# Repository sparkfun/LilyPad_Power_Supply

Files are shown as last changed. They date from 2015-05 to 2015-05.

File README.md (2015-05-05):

LilyPad Power Supply
========================================

LilyPad Power Supply

[*LilyPad Power Supply (DEV-11259)*](https://www.sparkfun.com/products/11259)

A small, but mighty power supply. This board was designed to be as small and inconspicuous as possible. 
Pop in a AAA battery, flip the power switch, and you will have a 5V supply to power your LilyPad circuit. 
Good up to 200mA. Short circuit protected.

Repository Contents
-------------------
 
* **/Hardware** - Eagle design files (.brd, .sch)
* **/Production** - Production panel files (.brd)

Documentation
--------------
* **[SparkFun Fritzing repo](https://github.com/sparkfun/Fritzing_Parts)** - Fritzing diagrams for SparkFun products.
* **[SparkFun 3D Model repo](https://github.com/sparkfun/3D_Models)** - 3D models of SparkFun products. 

License Information
-------------------
This product is _**open source**_! 

The **hardware** is released under [Creative Commons ShareAlike 4.0 International](https://creativecommons.org/licenses/by-sa/4.0/).

Please use, reuse, and modify these files as you see fit. Please maintain attribution to SparkFun Electronics and release anything derivative under the same license.

Distributed as-is; no warranty is given.

- Your friends at SparkFun.

_**Note:** A portion of this sale is given back to Dr. Leah Buechley for continued development and education of e-textiles._

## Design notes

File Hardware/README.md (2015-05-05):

SparkFun <PRODUCT NAME> Design Files
=====================================

The .sch and .brd files hare are Eagle CAD schematic and PCB design files from SparkFun Electronics.
A freeware version of Eagle can be found [here](http://www.cadsoftusa.com/download-eagle/freeware/). 

License
---------
This product is open source! 
The hardware is released under [Creative Commons ShareAlike 4.0 International](https://creativecommons.org/licenses/by-sa/4.0/).

Please use, reuse, and modify these files as you see fit. Please maintain attribution to SparkFun Electronics and release anything derivative under the same license.

Distributed as-is; no warranty is given.

- Your friends at SparkFun.

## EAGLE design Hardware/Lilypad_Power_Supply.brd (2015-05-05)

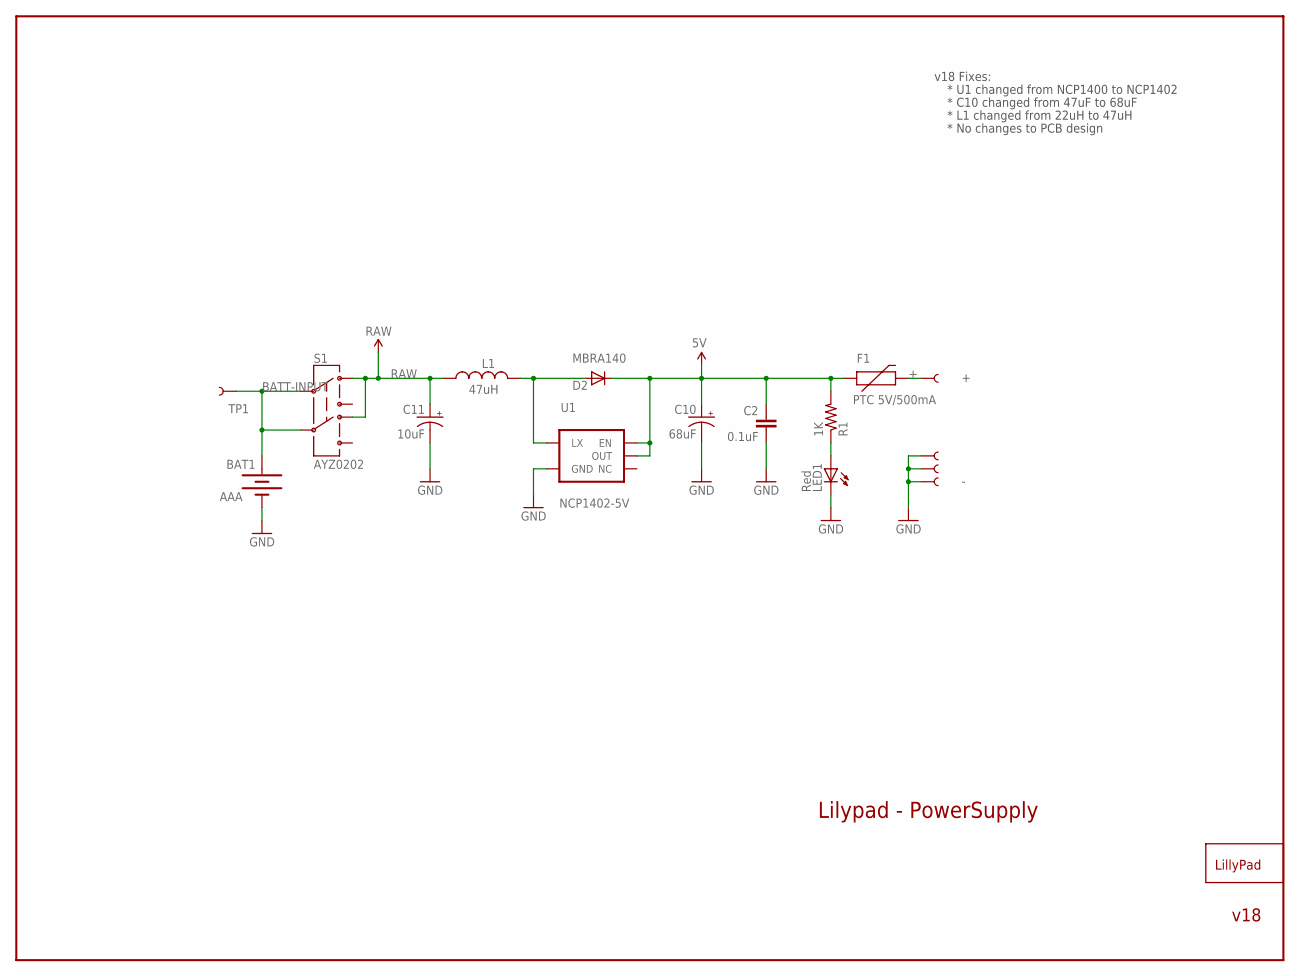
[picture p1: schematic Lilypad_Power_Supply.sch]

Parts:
BAT1: AAA; BATTERY-AAA
C2: 0.1uF; 0603-CAP
C10: 68uF; EIA3528-21
C11: 10uF; CPOL_1206
D2: MBRA140; SMA-DIODE
F1: PTC 5V/500mA; PTC-1206
L1: 47uH; CR54
LED1: Red; LED-1206
R1: 1K; 0603-RES
S1: AYZ0202
TP1: TEST-POINT3X5; PAD.03X.05
U1: NCP1402-5V; SOT23-5
U$1, U$2, U$4, U$5: SEWTAP10; PETAL-LONG-2-2SIDE
U$7: LOGO-LPLP; LOGO-LILYPAD

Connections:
5V: C2.1, C10.A (+), D2.C, F1.1, R1.2, U1.1 (EN), U1.2 (OUT)
+: F1.2, U$1.1
BATT-INPUT: BAT1.PWR@1 (+), S1.2, S1.5, TP1.P$1
GND: BAT1.GND@1 (-), C2.2, C10.C (-), C11.C (-), LED1.C, U1.4 (GND), U$2.1, U$4.1, U$5.1
unnamed: LED1.A, R1.1
unnamed: D2.A, L1.P$1 (1), U1.5 (LX)
RAW: C11.A (+), L1.P$2 (2), S1.3 (1), S1.6 (4)

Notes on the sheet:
Lilypad - PowerSupply
v18
v18 Fixes:
* U1 changed from NCP1400 to NCP1402
* C10 changed from 47uF to 68uF
* L1 changed from 22uH to 47uH
* No changes to PCB design

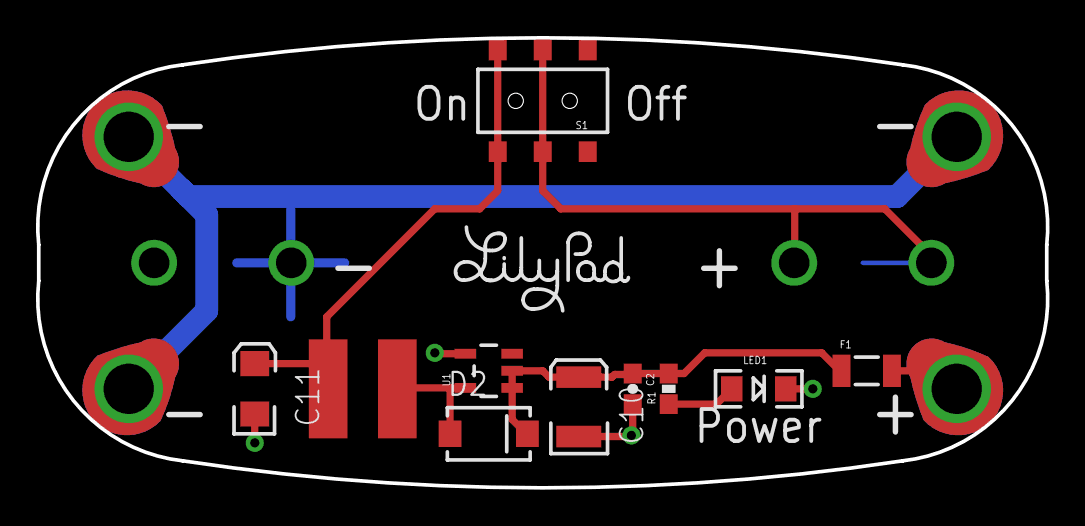
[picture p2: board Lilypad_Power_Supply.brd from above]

Board: 2 copper layers, 56.1 x 25.0 mm, 17 parts (1 on the bottom side), 7 nets.
